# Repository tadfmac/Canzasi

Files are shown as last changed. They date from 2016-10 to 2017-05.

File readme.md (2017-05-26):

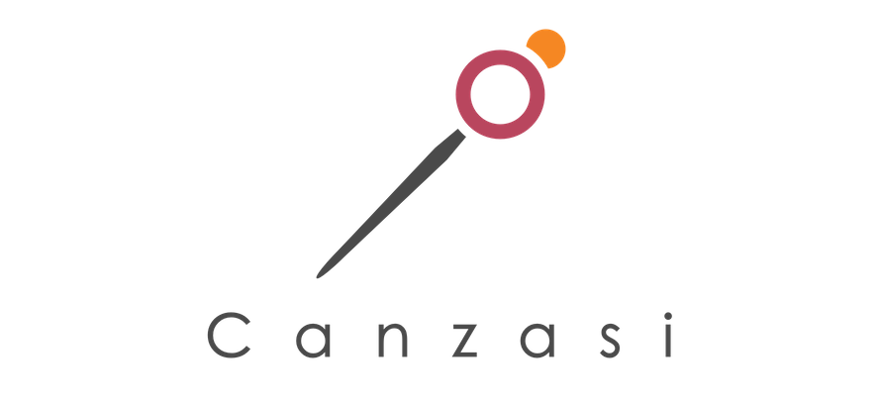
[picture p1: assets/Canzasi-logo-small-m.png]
Canzasi-logo


# Canzasi

「Canzasi」（かんざし）はArduinoを使ってI2C Slaveデバイスを試作するためのボードです。

# boards

## Canzasi-Prot

ATtiny841を採用した「Canzasi」最初のプロトタイプボードです。
Arduino IDEからISP経由での書き込みに対応しています。

### Concept

- Arduino IDE対応（ISP Programming）
- GROVEコネクタ
- ブレッドボードフレンドリー（1列GPIO）

### Design Data (v0.2)

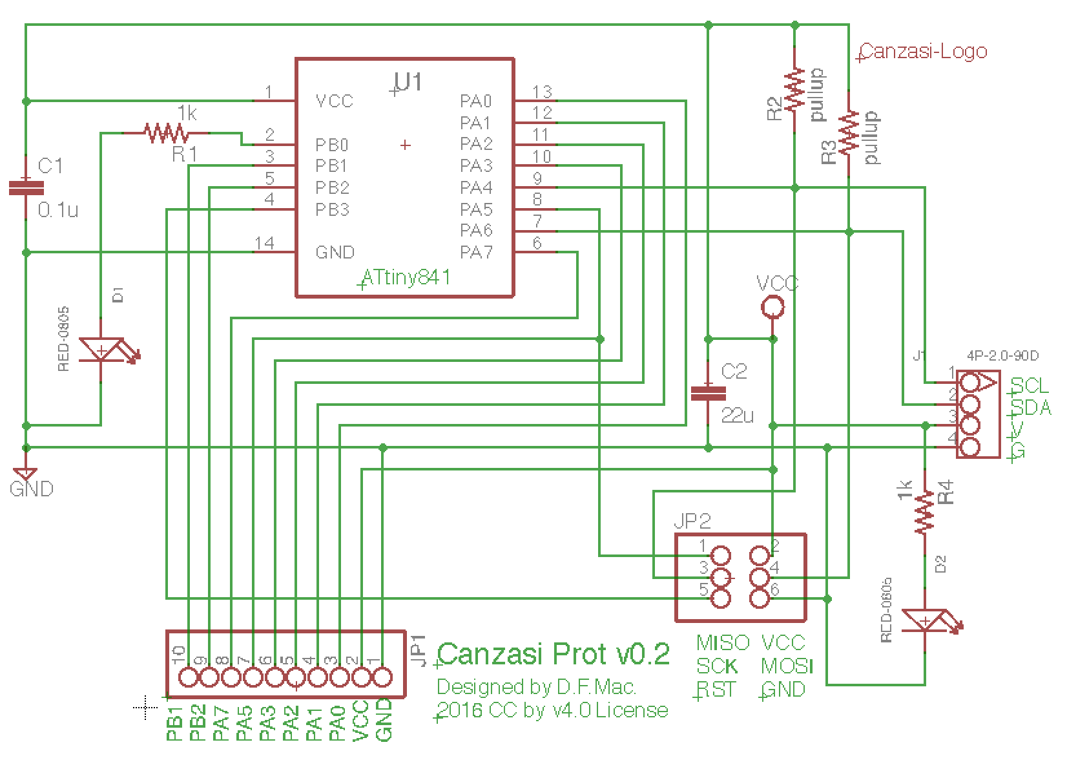
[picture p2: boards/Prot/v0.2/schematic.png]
schematic(v0.2)

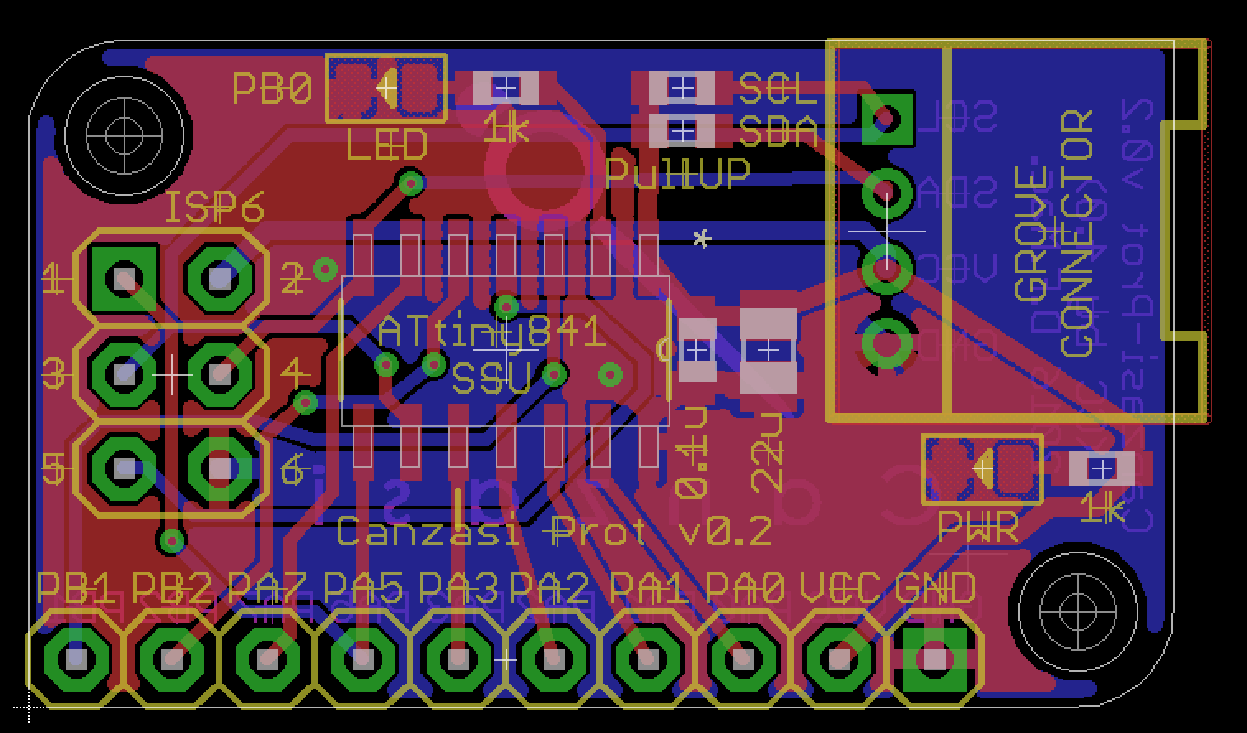
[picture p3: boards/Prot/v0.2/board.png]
board(v0.2)


[eagle files (v0.2)](./boards/Prot/v0.2/eagle/)

## Canzasi-Wrtr

Canzasi-Protにプログラムを書き込むためのArduino UNO用シールドです。

### Concept

- ミニマル
- Canzasi-Protとの接続にケーブル不要

### Design Data (v0.1)

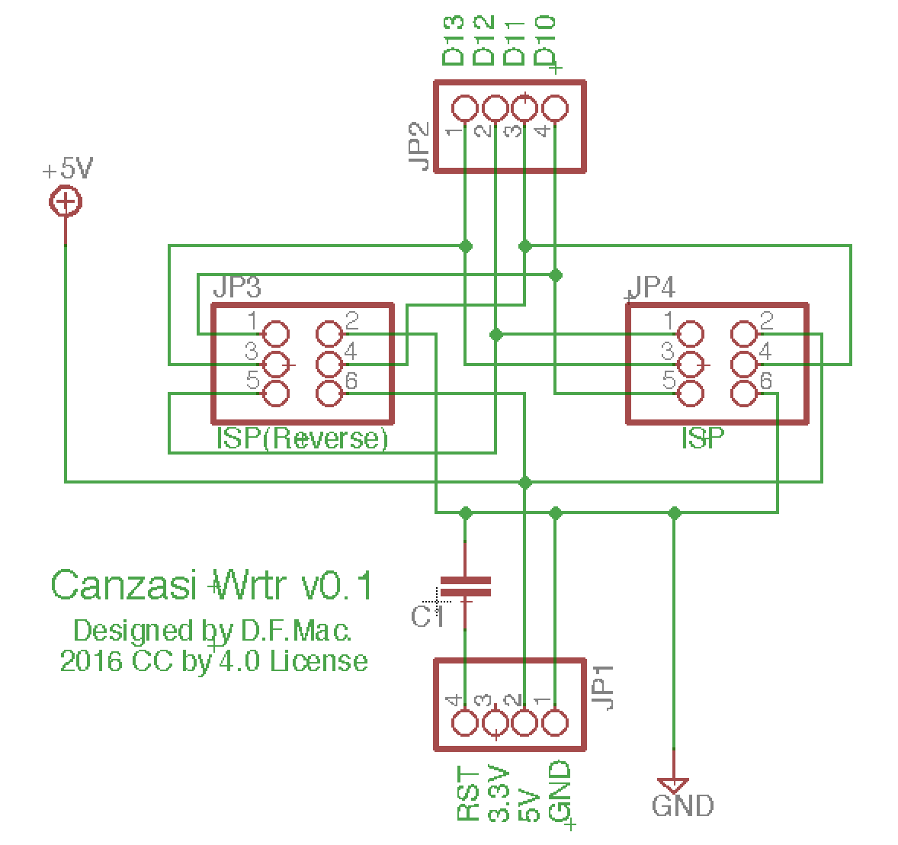
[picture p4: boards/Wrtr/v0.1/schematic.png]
schematic(v0.1)

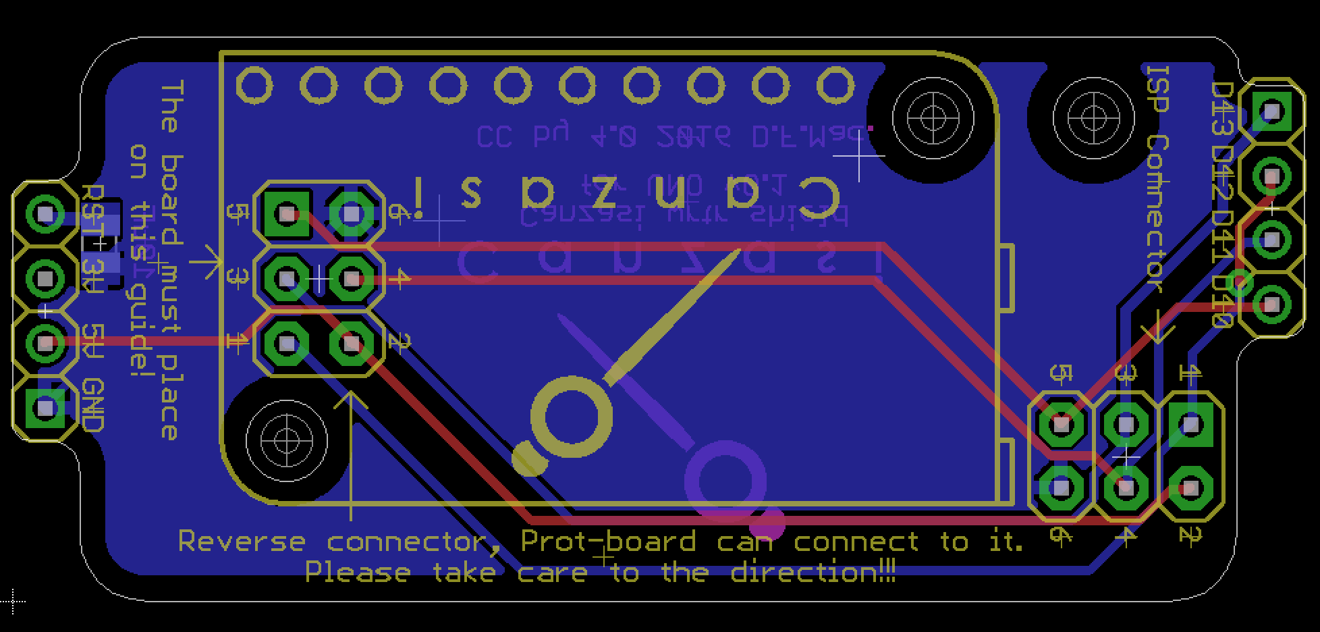
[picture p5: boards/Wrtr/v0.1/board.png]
board(v0.1)


[eagle files (v0.1)](./boards/Wrtr/v0.1/eagle/)

> v0.2に不具合 (#7) が見つかったため、一時的にstableをv0.1に戻しています。

## CHRMN-SimpleShield

Canzasiを搭載しいたCHIRIMEN用のシールドです。
外部に2つのGPIOしか出ていないこともあり、本ボードではATtiny841より安価なATtiny441を採用しています。

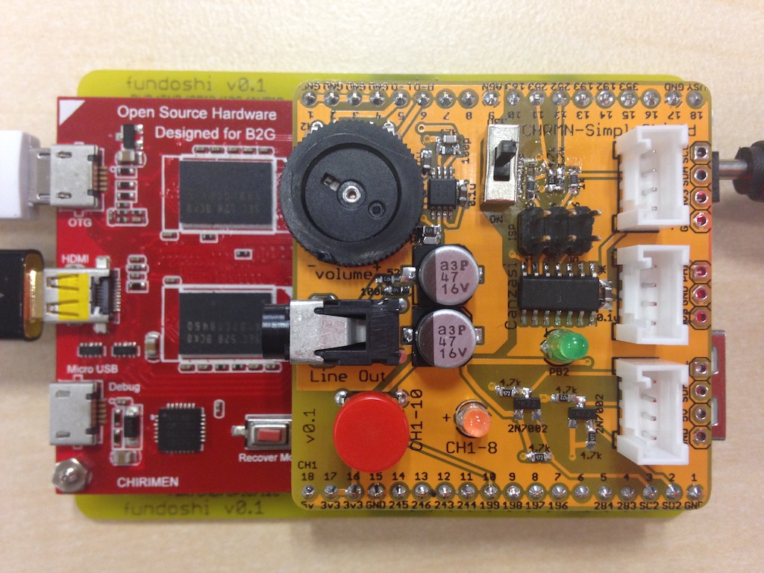
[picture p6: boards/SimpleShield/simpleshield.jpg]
simpleshield

※写真はv0.1のものです。

### Concept

- 小さなフットプリントでCHIRIMENの基本的な実験に必要な機能を全て搭載

### Design Data (v0.2)

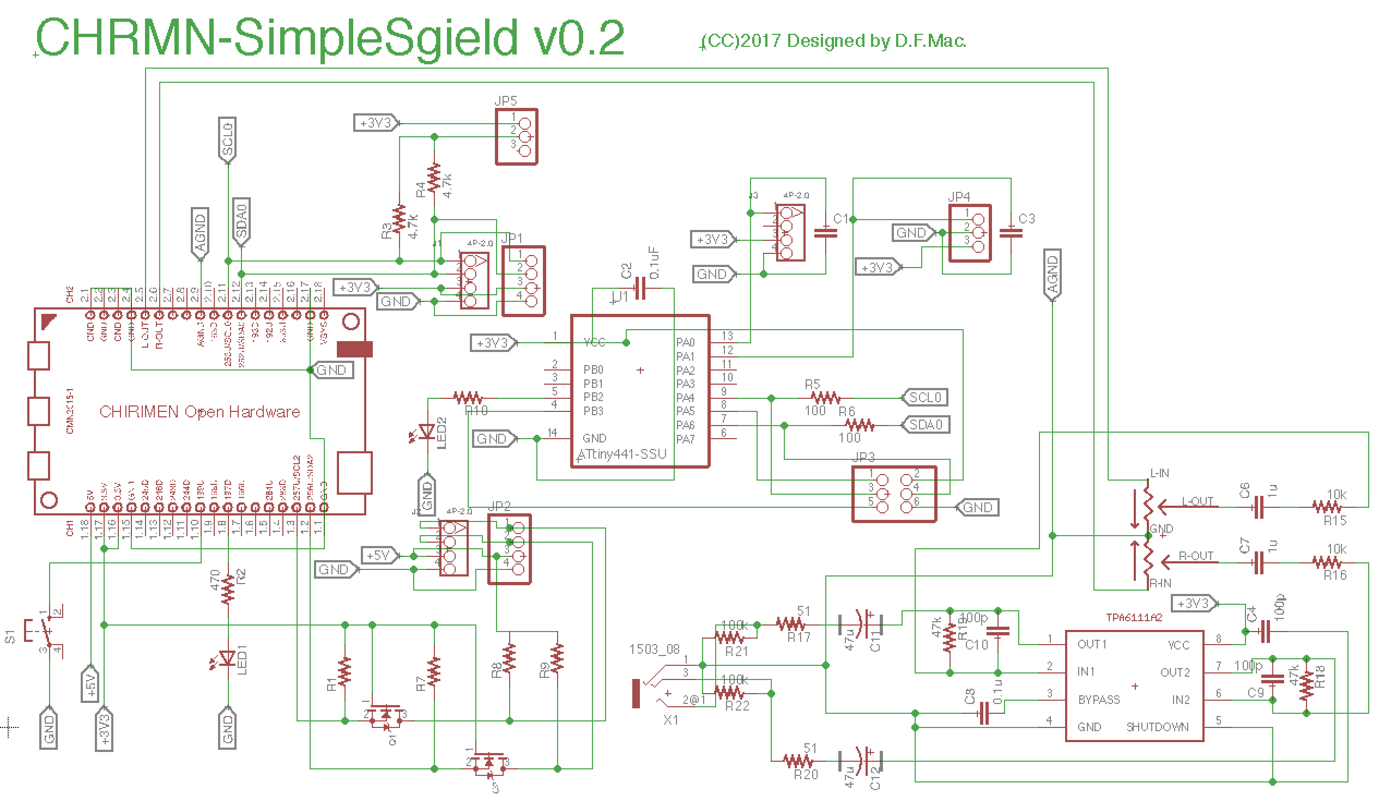
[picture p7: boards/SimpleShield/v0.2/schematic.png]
schematic(v0.2)

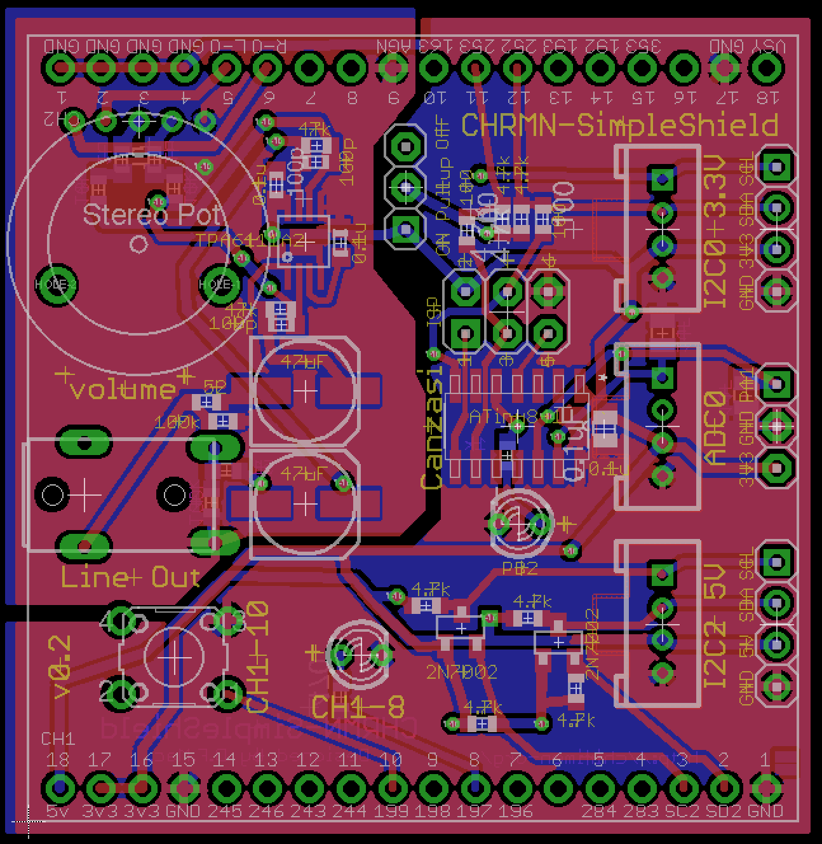
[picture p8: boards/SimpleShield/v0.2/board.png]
board(v0.2)


## Canzasi-Cont

CanzasiをベースにしたI2C接続ゲームパッドです。

### Concept

- ちいさい
- Groveコネクタで簡単に接続

### Design Data (v0.1)

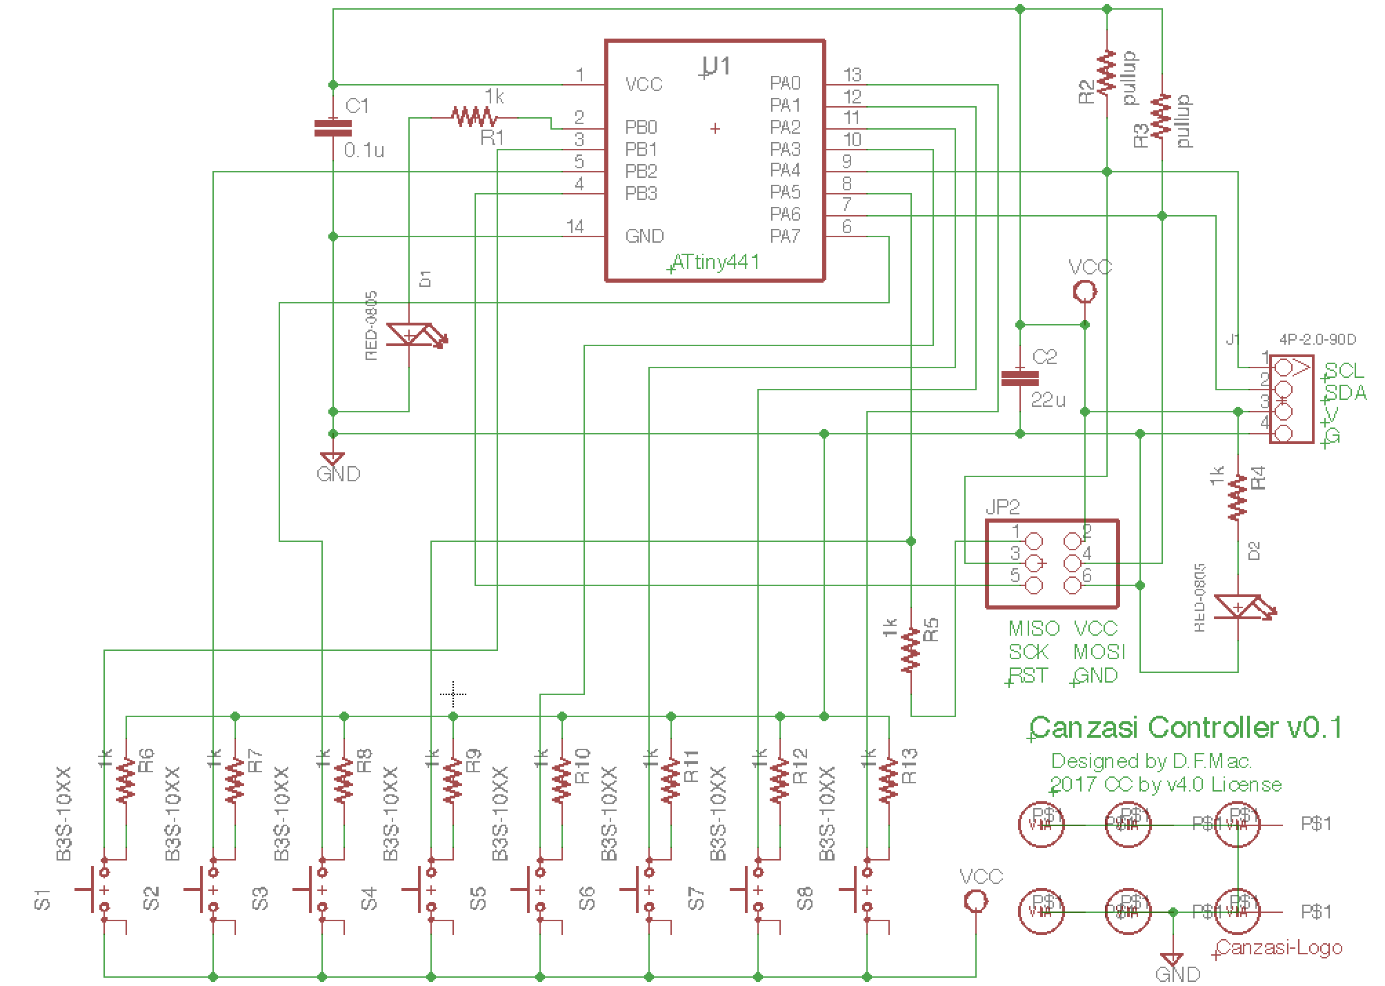
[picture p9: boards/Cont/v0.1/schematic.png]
schematic(v0.1)

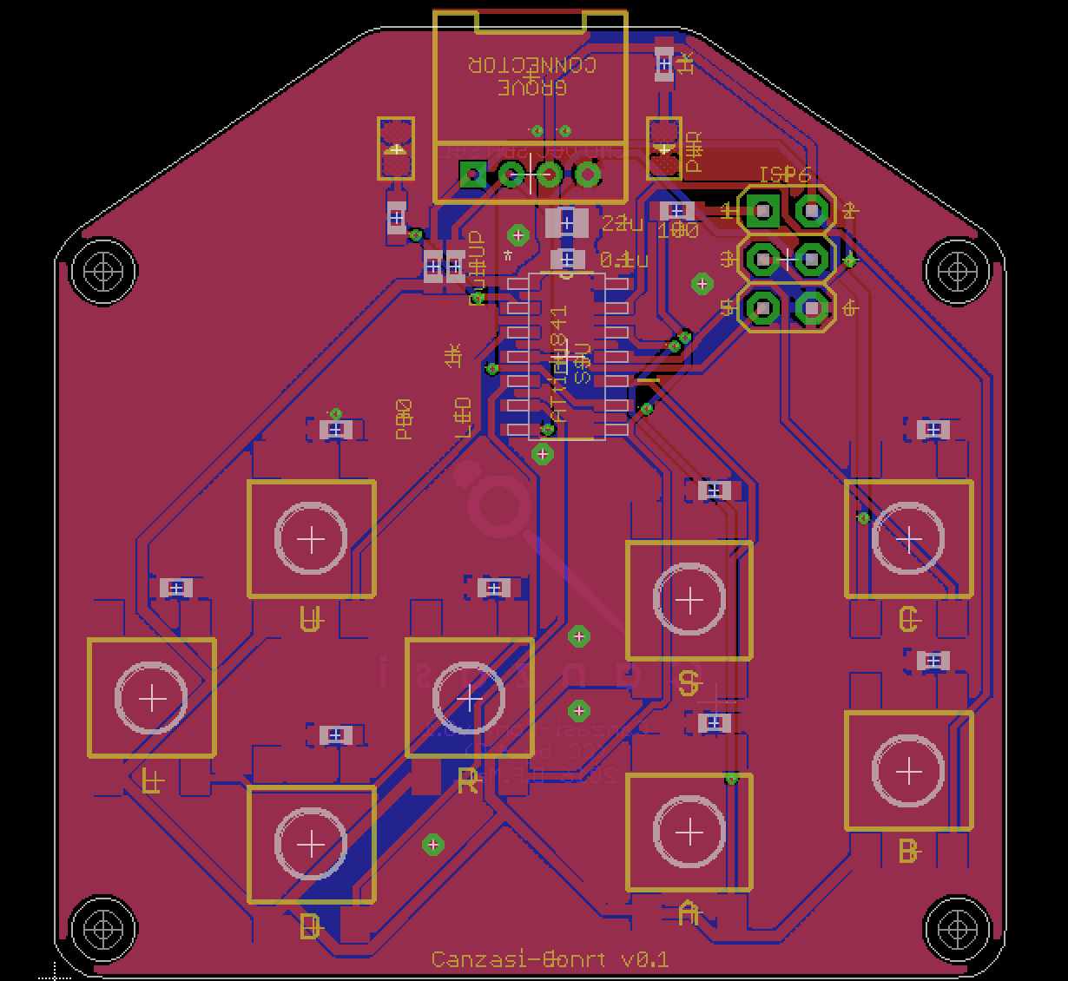
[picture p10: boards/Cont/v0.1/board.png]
board(v0.1)


[eagle files (v0.1)](./boards/Cont/v0.1/eagle/)

# examples

## [blink](./examples/blink/Canzasi_blink/Canzasi_blink.ino)

Canzasi用のLチカです。
これは単なるLチカで、I2Cデバイスではありません。

## [simpleAnalogDevice](./examples/simpleAnalogDevice/Canzasi/Canzasi_I2CAnalogDevice/Canzasi_I2CAnalogDevice.ino)

Masterからのread要求を受けてADC (10bit)の値を返すサンプルです。    
simpleAnalogDeviceを利用するマスターデバイスのサンプルコードはこちら（[Arduino用](./examples/simpleAnalogDevice/Master/Arduino/I2C_MasterWordReader/I2C_MasterWordReader.ino)）です。

## [simpleButtonDevice](./examples/simpleButtonDevice/Canzasi/Canzasi_I2CDataProvider/Canzasi_I2CDataProvider.ino)

Masterからのread要求を受けてButtonが押されているかどうかを返すサンプルです。    
simpleButtonDeviceを利用するマスターデバイスのサンプルコードはこちら（[Arduino用](./examples/simpleButtonDevice/Master/Arduino/I2C_MasterReader/I2C_MasterReader.ino)）です。

## [simpleLedDevice](./examples/simpleLedDevice/Canzasi/Canzasi_I2Cblink/Canzasi_I2Cblink.ino)

Masterからのwriteデータを受けてLEDの点灯と消灯を行うサンプルです。    
simpleLedDeviceを利用するマスターデバイスのサンプルコードはこちら（[Arduino用](./examples/simpleLedDevice/Master/Arduino/I2C_MasterWriter/I2C_MasterWriter.ino)）です。

## [combined_4_Analog_1](./examples/combined_4_Analog_1/Canzasi/Canzasi_combined_4_Analog_1/Canzasi_combined_4_Analog_1.ino)

4つのアナログボリューム（可変抵抗）を接続したデバイスです。
Masterからのwrite 1byte（4つのアナログボリュームのどの値を返すかを指定）の後にSRを経由した Read 1byteに対応して8bitのアナログボリュームのデータを返します。

combined_4_Analog_1を利用するマスターデバイスのサンプルコードはこちら（[CHIRIMEN用](./examples/combined_4_Analog_1/Master/chirimen/)）です。

## [combined_4_Analog_2](./examples/combined_4_Analog_2/Canzasi/Canzasi_combined_4_Analog_2/Canzasi_combined_4_Analog_2.ino)

4つのアナログボリューム（可変抵抗）を接続したデバイスです。
Masterからのwrite 1byte（4つのアナログボリュームを2つづつのセットにして、グループA、Bどちらの値を返すかを指定）の後にSRを経由した Read 2byteに対応して8bitのアナログボリューム2つ分のデータを返します。

combined_4_Analog_2を利用するマスターデバイスのサンプルコードはこちら（[CHIRIMEN用](./examples/combined_4_Analog_2/Master/chirimen/)）です。

# Licence

<br />このリポジトリで公開するプログラムソースコードやハードウエア設計情報は <a rel="license" href="http://creativecommons.org/licenses/by/4.0/">クリエイティブ・コモンズ 表示 4.0 国際 ライセンスの下に提供されています。</a>

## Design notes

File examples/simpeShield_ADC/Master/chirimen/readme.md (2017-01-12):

# Canzasi

[Canzasi_combined_2_ADC.ino](../../Canzasi/Canzasi_combined_2_ADC/Canzasi_combined_2_ADC.ino)と接続するCHIRIMEN用のサンプルアプリです。

このアプリを動作させるためには、このフォルダと同じ階層に、[Web I2C APIのPolyfill](https://github.com/club-wot/WebGPIO)から、下記ファイルを追加する必要があります。

- webi2c.js
- worker.js

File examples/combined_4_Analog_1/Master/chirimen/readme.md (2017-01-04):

# Canzasi

[Canzasi_combined_4_Analog_1.ino](../../Canzasi/Canzasi_combined_4_Analog_1/Canzasi_combined_4_Analog_1.ino)と接続するCHIRIMEN用のサンプルアプリです。

このアプリを動作させるためには、このフォルダと同じ階層に、[Web I2C APIのPolyfill](https://github.com/club-wot/WebGPIO)から、下記ファイルを追加する必要があります。

- webi2c.js
- worker.js

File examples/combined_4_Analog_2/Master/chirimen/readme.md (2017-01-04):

# Canzasi2

[Canzasi_combined_4_Analog_2.ino](../../Canzasi/Canzasi_combined_4_Analog_2/Canzasi_combined_4_Analog_2.ino)と接続するCHIRIMEN用のサンプルアプリです。

このアプリを動作させるためには、このフォルダと同じ階層に、[Web I2C APIのPolyfill](https://github.com/club-wot/WebGPIO)から、下記ファイルを追加する必要があります。

- webi2c.js
- worker.js

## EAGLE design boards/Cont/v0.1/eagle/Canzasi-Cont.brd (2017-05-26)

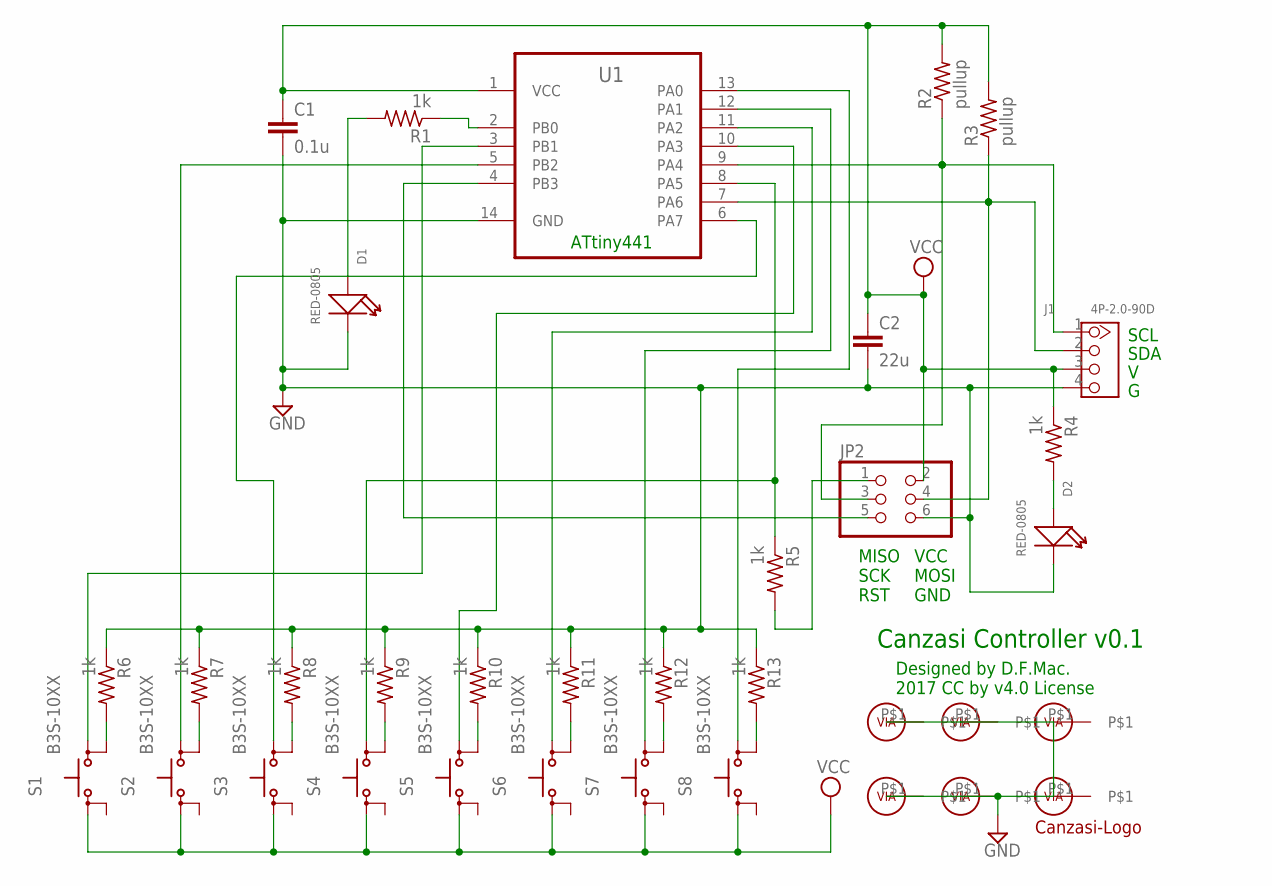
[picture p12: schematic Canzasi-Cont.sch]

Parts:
C1: 0.1u; C0603
C2: 22u; C0805
D1, D2: RED-0805; LED-0805
J1: 4P-2.0-90D; HW4-2.0-90D
JP2: PINHD-2X3; 2X03
R1, R4, R5, R6, R7, R8, R9, R10, R11, R12, R13: 1k; R0603
R2, R3: pullup; R0603
S1, S2, S3, S4, S5, S6, S7, S8: B3S-10XX
U1: ATTINY44A-SSU; SOIC127P600X175-14N
U$1: CANZASI-LOGOMEDIUM; CANZASI-LOGO-MEDIUM
U$2, U$3, U$4, U$5, U$6, U$7: VIA

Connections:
GND: C1.2, C2.2, D1.-, D2.-, J1.4, JP2.6, R6.1, R7.1, R8.1, R9.1, R10.1, R11.1, R12.1, R13.1, U1.14 (GND), U$2.P$1, U$3.P$1, U$4.P$1, U$5.P$1, U$6.P$1, U$7.P$1
unnamed: R1.1, U1.2 (PB0)
unnamed: D1.+, R1.2
unnamed: J1.2, JP2.4, R3.1, U1.7 (PA6)
unnamed: J1.1, JP2.3, R2.1, U1.9 (PA4)
unnamed: S1.3 (S), U1.3 (PB1)
unnamed: S2.3 (S), U1.5 (PB2)
unnamed: JP2.5, U1.4 (PB3)
unnamed: S3.3 (S), U1.6 (PA7)
unnamed: R5.1, S4.3 (S), U1.8 (PA5)
unnamed: S5.3 (S), U1.10 (PA3)
unnamed: S6.3 (S), U1.11 (PA2)
unnamed: S7.3 (S), U1.12 (PA1)
unnamed: S8.3 (S), U1.13 (PA0)
unnamed: D2.+, R4.2
unnamed: JP2.1, R5.2
unnamed: R6.2, S1.4 (S1)
unnamed: R7.2, S2.4 (S1)
unnamed: R8.2, S3.4 (S1)
unnamed: R9.2, S4.4 (S1)
unnamed: R10.2, S5.4 (S1)
unnamed: R11.2, S6.4 (S1)
unnamed: R12.2, S7.4 (S1)
unnamed: R13.2, S8.4 (S1)
VCC: C1.1, C2.1, J1.3, JP2.2, R2.2, R3.2, R4.1, S1.1, S2.1, S3.1, S4.1, S5.1, S6.1, S7.1, S8.1, U1.1 (VCC)

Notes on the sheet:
SCL
SDA
MISO SCK RST
VCC MOSI GND
ATtiny441
Canzasi Controller v0.1
Designed by D.F.Mac. 2017 CC by v4.0 License

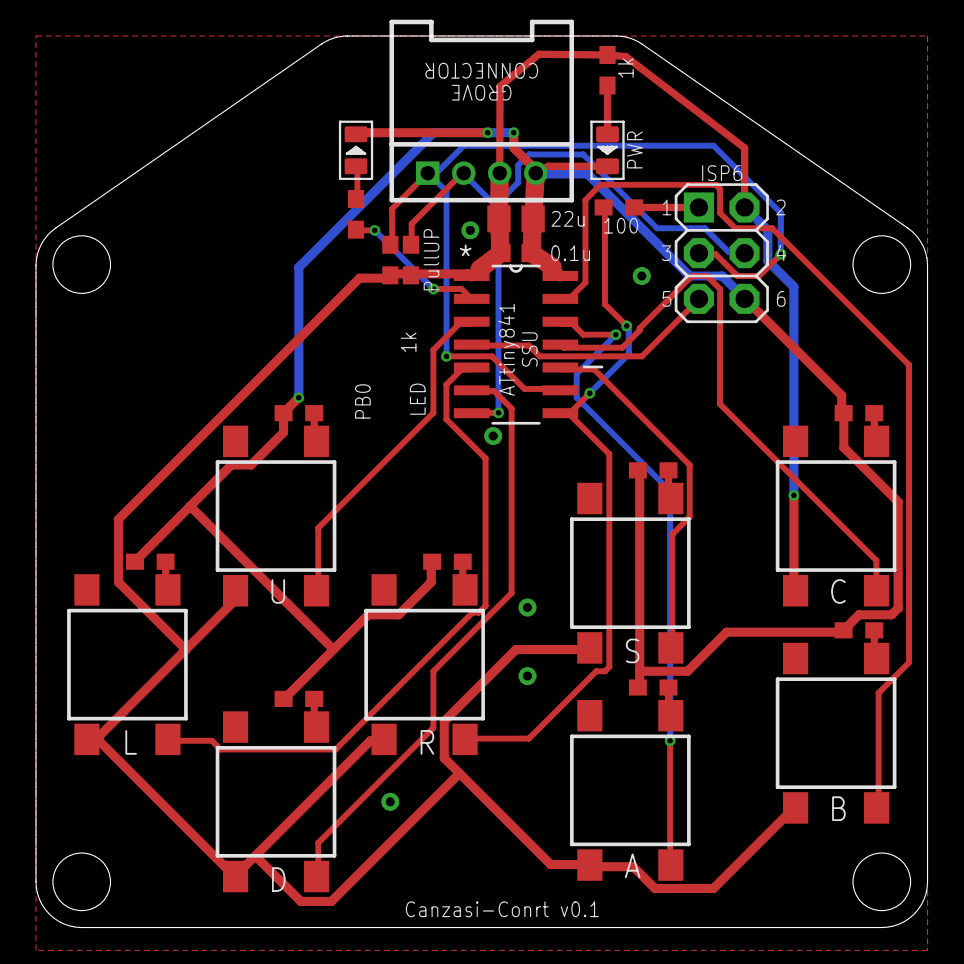
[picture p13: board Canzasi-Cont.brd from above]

Board: 2 copper layers, 49.5 x 49.5 mm, 35 parts (1 on the bottom side), 25 nets.

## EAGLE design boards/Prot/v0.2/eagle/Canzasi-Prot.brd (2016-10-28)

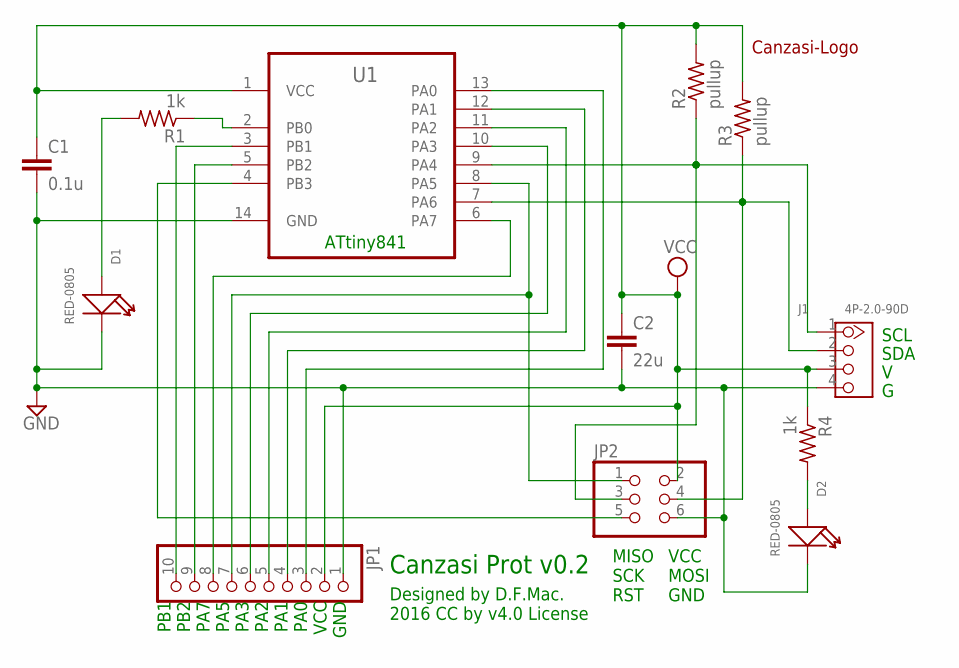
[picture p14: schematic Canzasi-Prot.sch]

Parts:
C1: 0.1u; C0603
C2: 22u; C0805
D1, D2: RED-0805; LED-0805
J1: 4P-2.0-90D; HW4-2.0-90D
JP1: PINHD-1X10; 1X10
JP2: PINHD-2X3; 2X03
R1, R4: 1k; R0603
R2, R3: pullup; R0603
U1: ATTINY44A-SSU; SOIC127P600X175-14N
U$1: CANZASI-LOGOMEDIUM; CANZASI-LOGO-MEDIUM

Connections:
GND: C1.2, C2.2, D1.-, D2.-, J1.4, JP1.1, JP2.6, U1.14 (GND)
unnamed: R1.1, U1.2 (PB0)
unnamed: D1.+, R1.2
unnamed: J1.2, JP2.4, R3.1, U1.7 (PA6)
unnamed: J1.1, JP2.3, R2.1, U1.9 (PA4)
unnamed: JP1.10, U1.3 (PB1)
unnamed: JP1.9, U1.5 (PB2)
unnamed: JP2.5, U1.4 (PB3)
unnamed: JP1.8, U1.6 (PA7)
unnamed: JP1.7, JP2.1, U1.8 (PA5)
unnamed: JP1.6, U1.10 (PA3)
unnamed: JP1.5, U1.11 (PA2)
unnamed: JP1.4, U1.12 (PA1)
unnamed: JP1.3, U1.13 (PA0)
unnamed: D2.+, R4.2
VCC: C1.1, C2.1, J1.3, JP1.2, JP2.2, R2.2, R3.2, R4.1, U1.1 (VCC)

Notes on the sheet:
SCL
SDA
MISO SCK RST
VCC MOSI GND
PB1 PB2 PA7 PA5 PA3 PA2 PA1 PA0 VCC GND
ATtiny841
Canzasi Prot v0.2
Designed by D.F.Mac. 2016 CC by v4.0 License

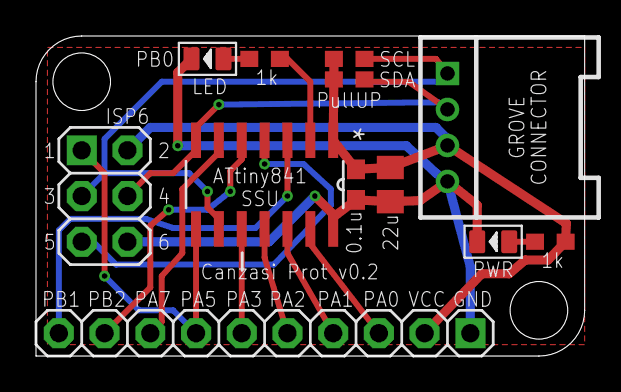
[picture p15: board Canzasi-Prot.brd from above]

Board: 2 copper layers, 30.5 x 17.8 mm, 13 parts (1 on the bottom side), 16 nets.

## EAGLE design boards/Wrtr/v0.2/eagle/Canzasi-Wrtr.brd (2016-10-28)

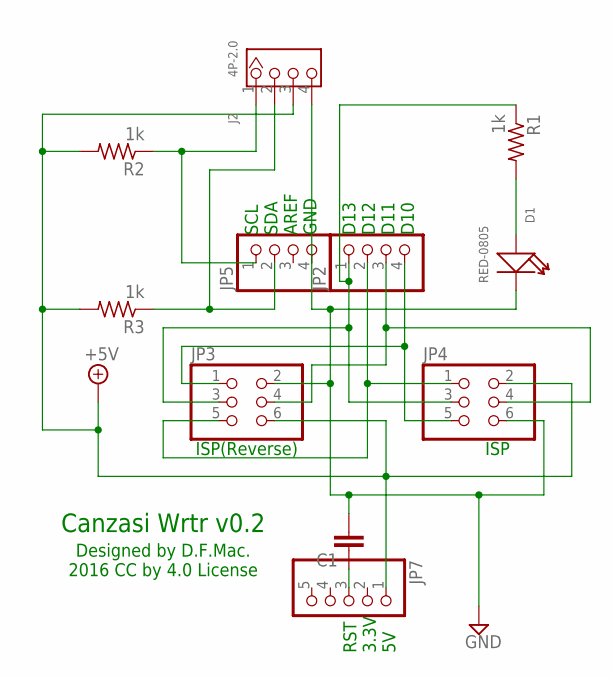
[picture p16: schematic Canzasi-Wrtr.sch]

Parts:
C1: C-EUC0805; C0805
D1: RED-0805; LED-0805
J2: 4P-2.0; HW4-2.0
JP2, JP5: PINHD-1X4; 1X04
JP3, JP4: PINHD-2X3; 2X03
JP7: PINHD-1X5; 1X05
R1, R2, R3: 1k; R0603

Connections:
+5V: J2.3, JP3.6, JP4.2, JP7.1, R2.2, R3.2
GND: C1.2, D1.-, J2.4, JP3.2, JP4.6, JP5.4
unnamed: JP2.4, JP3.1, JP4.5
unnamed: C1.1, JP7.3
unnamed: J2.1, JP5.1, R2.1
unnamed: JP2.1, JP3.3, JP4.3, R1.1
unnamed: JP2.2, JP3.5, JP4.1
unnamed: JP2.3, JP3.4, JP4.4
unnamed: J2.2, JP5.2, R3.1
unnamed: D1.+, R1.2

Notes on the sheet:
RST 3.3V 5V
SCL SDA AREF GND D13 D12 D11 D10
ISP
ISP(Reverse)
Canzasi Wrtr v0.2
Designed by D.F.Mac. 2016 CC by 4.0 License

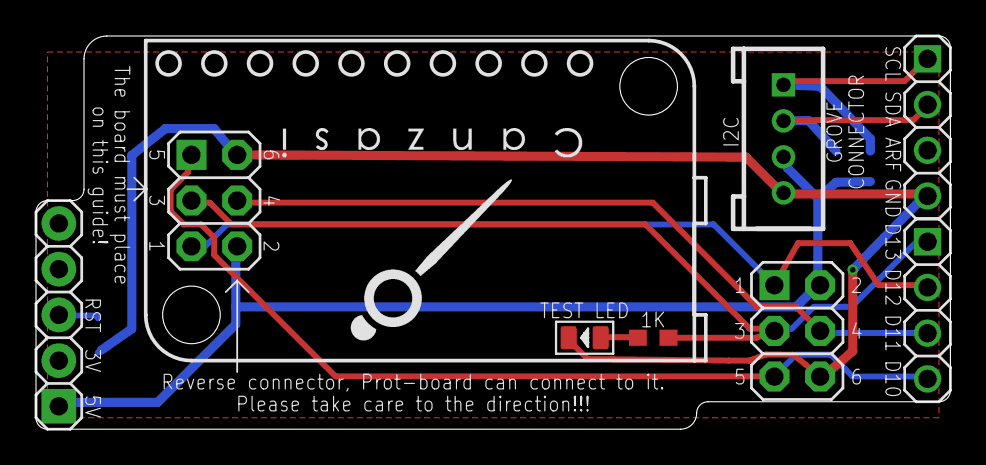
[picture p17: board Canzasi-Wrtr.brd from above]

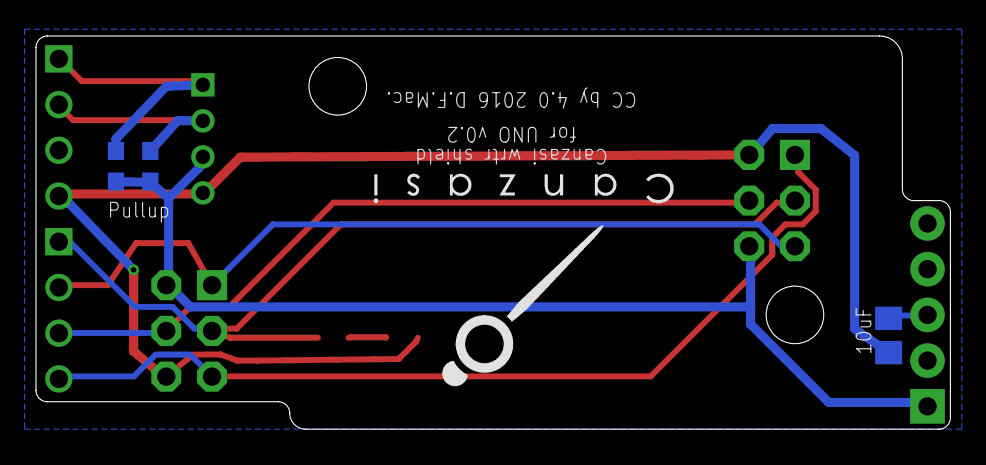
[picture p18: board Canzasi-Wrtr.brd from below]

Board: 2 copper layers, 50.8 x 21.8 mm, 13 parts (4 on the bottom side), 10 nets.

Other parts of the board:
U$1, U$2: CANZASI-LOGOMEDIUM; CANZASI-LOGO-MEDIUM

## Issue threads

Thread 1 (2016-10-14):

Prot Board

tadfmac, 2016-10-14:
最初のProt BoardのSpecを検討する

- [x] 仕様検討
- [x] PCBデザイン
- [x] ボード発注
- [x] 試作
- [x] テスト

tadfmac, 2016-10-14:
下記で行ってみる予定。動作確認できたらCloseします。

- MCU: ATtiny841 8Mhz
- VCC: 3.3V/5V 対応。(レギュレータなし)
- ISP端子（2x3PIN みLコネクタ）
- GROVEコネクタ（I2C）
- I2C端子である A4, A6はGPIOを出さない
- ISP書き込みなのでResetピン（B3）は空ける
- 2.54mm 1列GPIO (VCC、GND、A0、A1、A2、A3、A5、A7、B0、B1、B2)

tadfmac, 2016-10-16:
デザイン完了
https://github.com/tadfmac/Canzasi/tree/master/boards/Prot/v0.1/eagle

tadfmac, 2016-10-18:
10/18にelecrowに発注

tadfmac, 2016-10-28:
残念ながらv0.1には不具合があったが、#5の内容を修正しての動作確認完了。
修正版 (v0.2) の設計後、elecrowに再発注中。
一旦動作確認まで完了しているので、Close。

Closed 2016-10-28.

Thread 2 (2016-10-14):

ISP Writer

tadfmac, 2016-10-14:
推奨ISPライターを検討する

- [x] 候補洗い出し
- [x] 検討
- [x] 推奨ライターをトップページに記載

tadfmac, 2016-10-14:
# 個人的な意見

AVRISPなどを買ってもいいけど、同じ値段出せばArduino UNO買えるし、Arduino UNOとブレッドボード、ケーブルがあればISP書き込みにも使えるので汎用性が高い。
なので、とりあえずUNO買っとけと言いたい。（ISPシールド等の導入は、頻繁にATtinyなどを扱うようになってからでいいと思う）

tadfmac, 2016-10-18:
推奨は上記 2.。理由は上記の通り。
ただし、現状国内でISPシールドの選択肢が 少ないので、自作方法も含めて情報展開する。
AI追加。

tadfmac, 2016-10-28:
ISPライターとして、
- （シンプルな）Canzasi:wrtr v0.1
- （I2C Masterテスト用にも利用可能な）Canzasi:wrtr v0.2
を公開したのでClose。

Closed 2016-10-28.

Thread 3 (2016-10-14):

ビルド方法

tadfmac, 2016-10-14:
を書く

tadfmac, 2016-10-14:
# Core

- [SpenceKonde/ATTinyCore](https://github.com/SpenceKonde/ATTinyCore)

# I2C Library

- [orangkucing/WireS](https://github.com/orangkucing/WireS)

tadfmac, 2016-10-18:
# Setup with Arduino IDE 1.6.12

1. Download and install [Arduino IDE 1.6.12](https://www.arduino.cc/en/Main/Software)
2. Add ATtiny841 configulation to avrdude.conf (see also [revised avrconf](https://github.com/tadfmac/Canzasi/blob/master/Arduino/hardware/tools/avr/etc/avrdude.conf)'s last section)
3. Download and install [SpenceKonde/ATTinyCore](https://github.com/SpenceKonde/ATTinyCore/blob/master/Installation.md)

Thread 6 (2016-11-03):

i2c841s2.h is not support register->data device

tadfmac, 2016-11-03:
now only support :
[s]->[a(w)]->[d]->[p]->callback(d)  or
[s]->[a(w)]->[d/d/d]->[p]->callback(d/d/d)
and also:
[s]->[a(w)]->[d]->[p]->callback(d)->[s]->[a(r)]->[d(send 1byte)]->[p]
but:
[s]->[a(w)]->[d]->callback(d)->[sr]->[a(r)]->[d(send 1byte)]->[p]
is not supported now.

tadfmac, 2016-11-04:
Completed!

Closed 2016-11-04.

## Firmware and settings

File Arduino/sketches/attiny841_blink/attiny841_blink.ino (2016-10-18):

// Blink for Canzasi-Prot(ATtiny841)
// with https://github.com/SpenceKonde/ATTinyCore
// 
// License CC by 4.0 2016 D.F.Mac.
//
//                   +----+
//                VCC|    |GND
// LED    PB0/A11/ D0|    |D10/A0 /PA0
//        PB1/A10/ D1|    |D9 /A1 /PA1
//        PB3/ A9/D11|    |D8 /A2 /PA2
//        PB2/ A8/ D2|    |D7 /A3 /PA3
//        PA7/ A7/ D3|    |D6 /A4 /PA4
//        PA6/ A6/ D4|    |D5 /A5 /PA5
//                   +----+
//

#define LED_PIN 0 // PB0

void setup() {
  // put your setup code here, to run once:
  pinMode(LED_PIN,OUTPUT);
}

void loop() {
  // put your main code here, to run repeatedly:
  digitalWrite(LED_PIN,HIGH);
  delay(1000);
  digitalWrite(LED_PIN,LOW);
  delay(1000);
}

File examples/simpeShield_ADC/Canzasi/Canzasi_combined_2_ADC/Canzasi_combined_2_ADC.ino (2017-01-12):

// Canzasi_I2CAnalogDevice
// 2 8bit ADC examnple
//   
// with https://github.com/SpenceKonde/ATTinyCore
// 
// License CC by 4.0 2016 D.F.Mac.
//
//                   +----+
//                VCC|    |GND
//        PB0/A11/ D0|    |D10/A0 /PA0    ANALOG_CH_1
//        PB1/A10/ D1|    |D9 /A1 /PA1    ANALOG_CH_2
//        PB3/ A9/D11|    |D8 /A2 /PA2    
// LED    PB2/ A8/ D2|    |D7 /A3 /PA3    
//        PA7/ A7/ D3|    |D6 /A4 /PA4    SCL
// SDA    PA6/ A6/ D4|    |D5 /A5 /PA5
//                   +----+
//
#include "i2c841s2.h"

// Constants
#define LED_PIN 2

#define ANALOG_CH1 0
#define ANALOG_CH2 1
#define REGISTER_MIN 0x10
#define REGISTER_MAX 0x11
#define ADC_CHANNELS 2
#define TX_BUFFER_SIZE 1
const int analog_pins[ADC_CHANNELS] = {ANALOG_CH1,ANALOG_CH2};

// Global Valiables
static uint8_t tx_data[ADC_CHANNELS] = {0x20,0x21};
static int currentCh = 0;

static void onI2CWrite(uint8_t *pbuf, uint8_t len){
  digitalWrite(LED_PIN,HIGH);
  uint8_t data = *(pbuf + (len -1));
  if((data >= REGISTER_MIN)&&(data <= REGISTER_MAX)){
    currentCh = data- 0x10;
    i2cs.setTxBuffer(&tx_data[currentCh],TX_BUFFER_SIZE);
  }  
  digitalWrite(LED_PIN,LOW);
}

void setup() {
  pinMode(LED_PIN,OUTPUT);

  digitalWrite(LED_PIN,HIGH);
  delay(100);
  digitalWrite(LED_PIN,LOW);
  delay(100);
  digitalWrite(LED_PIN,HIGH);
  delay(100);
  digitalWrite(LED_PIN,LOW);
  delay(100);
  digitalWrite(LED_PIN,HIGH);
  delay(100);
  digitalWrite(LED_PIN,LOW);
  delay(100);  

  i2cs.setTxBuffer(&tx_data[currentCh],TX_BUFFER_SIZE);
  i2cs.setOnWriteEnd(onI2CWrite);
  i2cs.init(0x30);            
}

void loop() {
  int cnt,adc;
  uint8_t data;

  for(cnt = 0;cnt < ADC_CHANNELS;cnt ++){
    adc = analogRead(analog_pins[cnt]);
    data = (uint8_t)(adc >> 2);
    tx_data[cnt] += (data - tx_data[cnt]) / 2;
  }
  delay(30);
}

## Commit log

2016-10-14 wip: 10/14 buckup
2016-10-16 add Prot board info(v0.1)
    [Canzasi-Prot.brd, Canzasi-Prot.sch]
2016-10-18 revise samples and fix library
    [I2C_MasterHelloWorld.ino, attiny841_blink.ino]
2016-10-18 add Wrtr v0.1
    [Canzasi-Wrtr.brd, Canzasi-Wrtr.sch]
2016-10-28 Prot/Wrtr : update v0.2 (fix issue #5)
    [Canzasi-Prot.brd, Canzasi-Prot.sch, Canzasi-Wrtr.brd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]
2016-11-03 add example for analog devices
2016-12-13 i2c841s2.h: fix bug
2017-03-23 add SimpleShield design data
    [SimpleShield.brd, SimpleShield.sch]
2017-05-26 add Canzasi-Cont v0.1 files
    [Canzasi-Cont.brd, Canzasi-Cont.sch]
